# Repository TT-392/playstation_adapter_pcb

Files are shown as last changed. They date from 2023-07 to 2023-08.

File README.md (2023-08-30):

# RP2040 PlayStation adapter
This project is a simple PlayStation 1/2 controller port to USB C adapter. I made it so that I would be able to use it with the cheap, second hand, PlayStation 2, Taiko no Tatsujin drum, which I bought while in Japan.

I only wrote software for the Taiko drum, but in theory, all of the hardware is there to support a lot of different kinds of PlayStation controllers. The firmware can be found [here](https://github.com/TT-392/playstation_adapter_code).

## Using the hardware with non Taiko drum controllers
If you want to use this hardware with other PlayStation controllers, you are going to have to write your own firmware. For details on how to do this, I recommend the following source: [Interfacing a PS2 (PlayStation 2) Controller](https://store.curiousinventor.com/guides/PS2/).

One thing to keep in mind is power requirements of the controller you are using. I haven't found much information on how much power controllers pull (not that I put in that much effort), except for what is mentioned in the aforementioned source. Therefore, I can only give information on the power supply situation of this PCB.
* Pin 5 (power). This pin gets 3.3V through an AMS1117-3.3 voltage regulator. This voltage regulator is rated for 1A (though, this does assume that it is able to get rid of the heat), but that does assume that your USB port is able to supply that. Therefore, its power rating is, whatever your USB port is able to deliver if that is < 1A, otherwise 1A.
* Pin 3 (vibrator power). This pin is connected to the USB port VBUS pin (5V) through a 0 ohm resistor, so it can be enabled or disabled by placing or not placing that resistor. I don't know how this pin is usually used, because I only have a Taiko drum, and that drum doesn't have a vibration motor, but it felt like a good idea to give the option to leave it unconnected in case there exists a controller which pulls too much power for a USB port with the vibration motor powered, but not without it powered (assuming the controller would even work like that).
* I referred to USB power in those last 2 points. This table on [Wikipedia](https://en.wikipedia.org/wiki/USB#Power) should help you in figuring out what that is. Keep in mind that the type-c power delivery standards need extra communication between your device and the supply, and therefore cannot be used in this case. While with the BC 1.1 and 1.2 specs, you are supposed to check if there is a resistor between the D+ and D- lines to check if you are allowed to pull that much power, this PCB doesn't have the hardware to check that, but (although it is probably a bad idea), nothing is stopping you from pulling that much from ports capable of this.

## Ordering
I used JLCPCB to order my PCBs with all of their parts already pick and placed. I used [this](https://github.com/Bouni/kicad-jlcpcb-tools) plugin to do this. However, if you just want to order the same PCBs as I did, without any modifications, you can just grab the production files from the "JLCPCB" folder, or from the "releases" tab on github. The rest of this guide assumes you have your PCBs with the SMD components fully assembled at JLCPCB (nothing is stopping you from soldering them on yourself of course).

Apart from the PCBs, you should get your hands on some PlayStation controller ports with 90 degree pins. I got mine from [AliExpress](https://www.aliexpress.com/item/32818887920.html?spm=a2g0o.order_list.order_list_main.17.45ed1802iEjUwq) (AliExpress links rot quickly, but you should be able to find something similar). And some 9 pin, 3.96mm pitch pin header, I used [these](https://www.lcsc.com/product-detail/_BOOMELE-Boom-Precision-Elec-_C10586.html) (At the time of writing, you get free shipping on LCSC, if your recently ordered something from JLCPCB). And if you want some protection for your board, get some 50mm diameter heat-shrink (I got [this](https://www.aliexpress.com/item/1005002849810793.html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) stuff from AliExpress, seems to work well).

## assembly
If you followed the ordering instructions, you should now have a PCB that looks something like one of these:

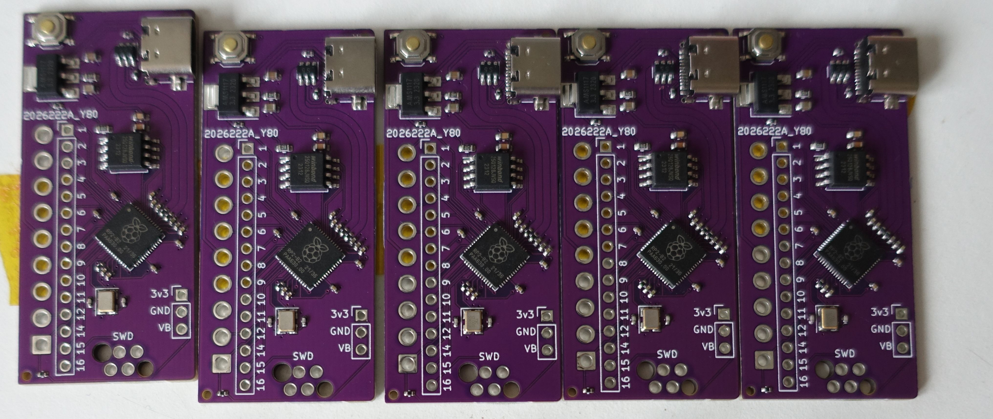
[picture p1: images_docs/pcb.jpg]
5 assembled PCBs with purple solder mask


Because the 90 degree PlayStation ports don't quite reach to the PCB, a we need something to bridge the gap. To do this, I decided to use some 3.96mm pitch, 9 pin pin headers, sadly, I couldn't find any without a plastic tab, so I just got the ones that looked like they had a tab that was easy to remove. So that is the first step in assembly, remove this tab, like is shown in the following image:

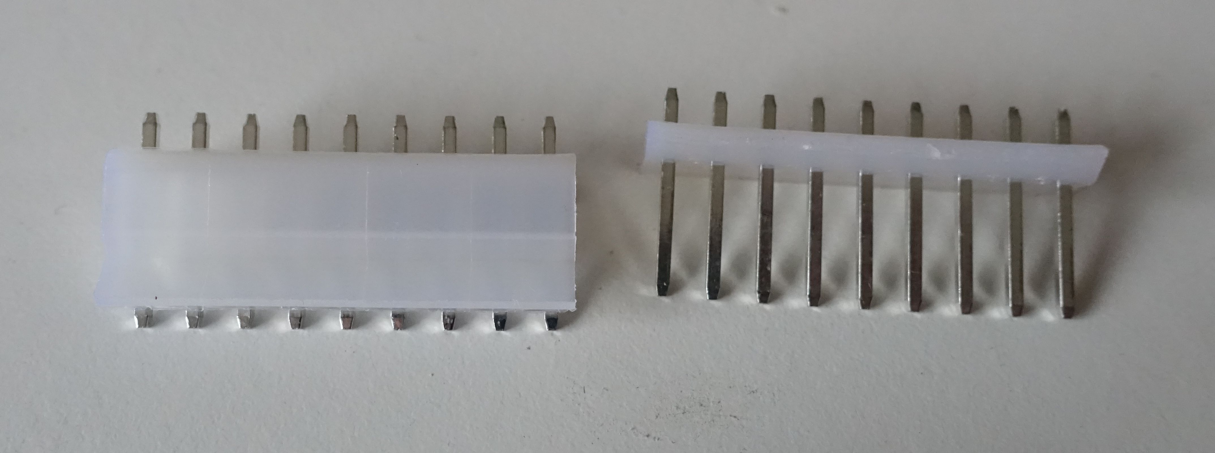
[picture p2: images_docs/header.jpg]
Two pin headers, one of them has the tab removed


Next, this header should be soldered to the PCB, I have found that it works best if you solder on the connector with the pins sticking out about 5 mm, and with the side of the connector that has the least plastic, pointing to the edge of the board, to allow for easier snipping later (I found out about this orientation trick in the next one I assembled, therefore the pictures have the connector rotated by 180 degrees compared to what I am saying here).

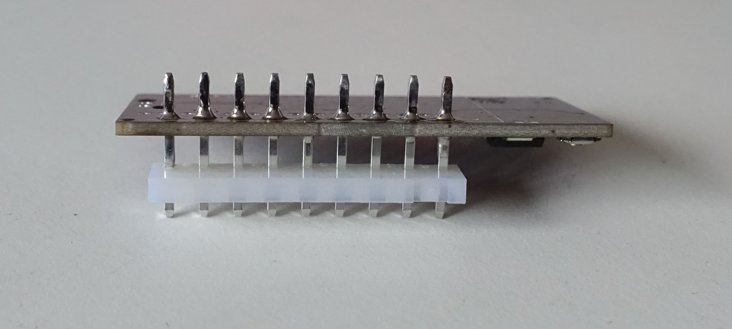
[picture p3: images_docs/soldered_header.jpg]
A side view of the PCB with the pin header installed, the plastic part of the pin header isn't flush with the surface of the PCB like it would normally be, but instead it is about 7 mm away from the surface.


Next, we glue (I used hot glue) the connector to the bottom side of the PCB, with the pins as close as possible to the pin header's pins, like shown in the following picture

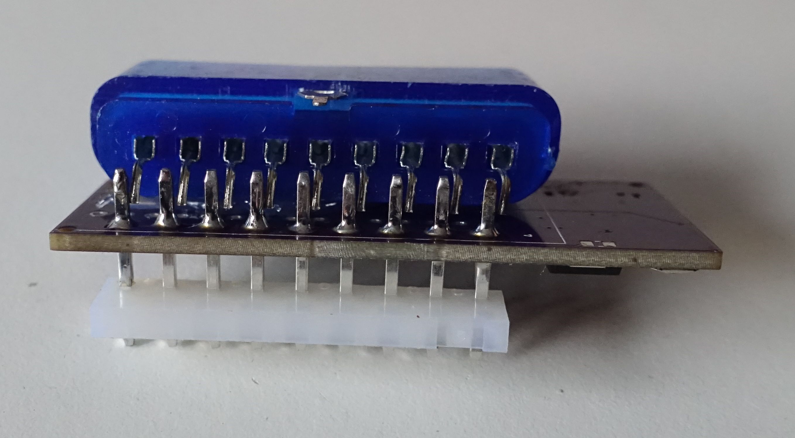
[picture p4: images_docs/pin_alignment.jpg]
Like the last picture, but with a blue PlayStation connector glued on the back of the PCB, close to touching the header pins from the side Like the last picture, but with a blue playstation connector glued on the back of the pcb, close to touching the header pins from the side


The next step is to solder these pins together, be sure to use ample solder, to make sure the pins really have a good connection.

After you have soldered these pins together, you can go ahead and use some side cutters to cut the pins of the connector on the other side of the board. The result of these two steps can be seen in the following image:

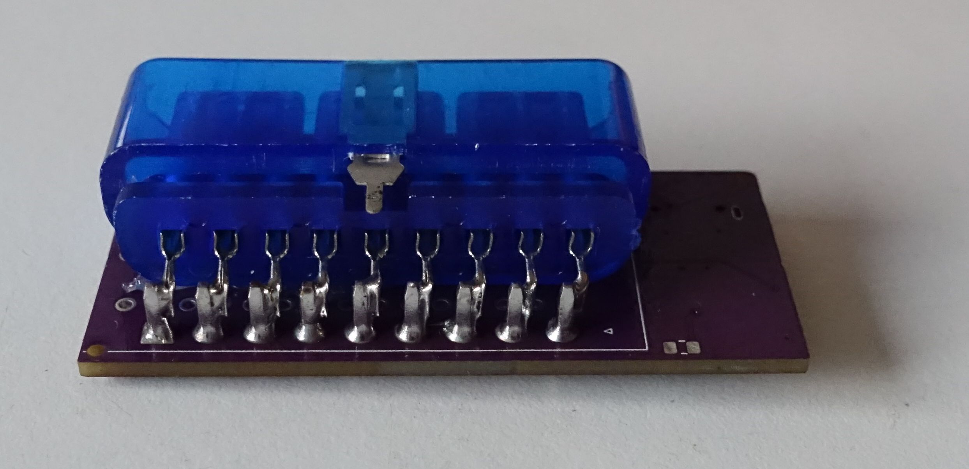
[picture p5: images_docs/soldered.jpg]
A view of the bottom side of the board, the pin header, and the PlayStation connector pins are soldered together. The excess part of the pin header on the other side of the board has been cut off A view of the bottom side of the board, the pin header, and the playstation connector pins are soldered together. The excess part of the pin header on the other side of the board has been cut off


Now it is time to heat shrink our adapter for some extra protection. Cut off a decent size piece of the heat shrink, so that the adapter can sit inside, with ample space on both sides:

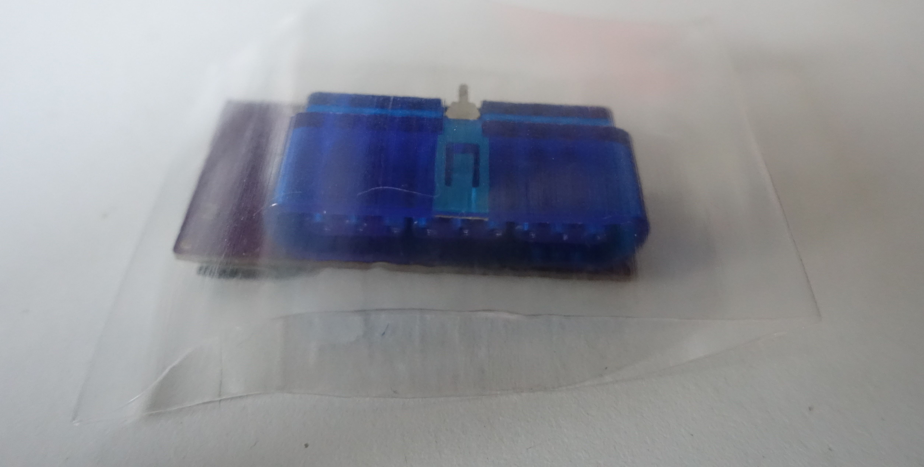
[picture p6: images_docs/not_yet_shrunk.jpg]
The assembled adapter sitting in a seemingly big piece of heat-shrink


Now use a heat gun to shrink the heat-shrink:

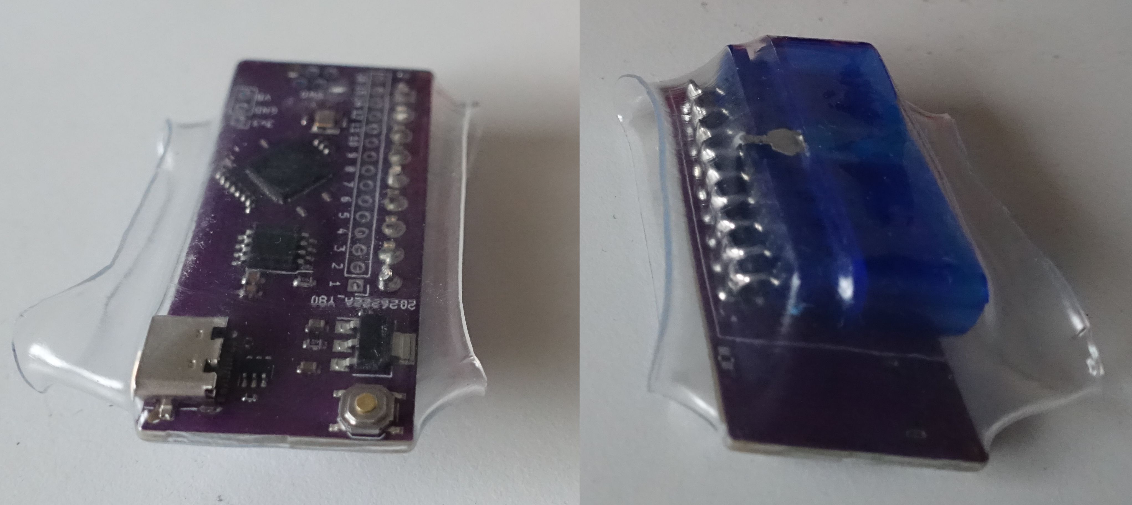
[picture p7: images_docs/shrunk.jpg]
The same as the previous image, but with the heat-shrink shrunk around the adapter


Now we can cut away the excess heat-shrink (I used normal scissors, just make sure they are scissors that close well), and we have our finished adapter:

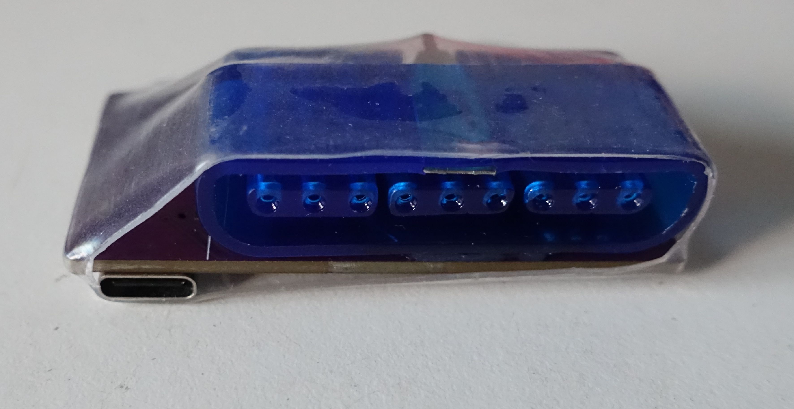
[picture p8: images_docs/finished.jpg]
The finished adapter


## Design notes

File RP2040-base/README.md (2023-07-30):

# RP2040-base
Basic drop in RP2040 kicad schematic sheet

# IMPORTANT
Not quite ready for use yet, for details, see notes.md.

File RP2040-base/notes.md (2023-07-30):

# Bugs
Not compliant with jlcpcb design rules
no explanation about the flash chip
Crystal is no longer a basic part? there seems to be a different 12MHz crystal in its place
jlcpcb doesn't have basic 27 ohm resistors

# Improvements
C4 could use a sligghtly better position (giving more space to GPIO0-7
U2 could be closer to U1
if chip were not at 45 degrees, that might have allowed for a smaller footprint
rp2040 3d model, add pi logo
jlcpcb part numbers

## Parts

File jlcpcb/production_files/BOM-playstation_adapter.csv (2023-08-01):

Comment | Designator | Footprint | LCSC
1k | R5 | R_0402_1005Metric | C11702
100n | C17 | C_0603_1608Metric | C14663
100n | C10,C11,C12,C3,C4,C5,C6,C7,C8,C9 | C_0402_1005Metric | C1525
30p | C15,C16 | C_0402_1005Metric | C1570
1u | C1 | C_0603_1608Metric | C15849
RP2040 | U3 | QFN-56-1EP_7x7mm_P0.4mm_EP3.2x3.2mm | C2040
1k | R6 | R_0603_1608Metric | C21190
1R | R1 | R_0603_1608Metric | C22936
27 | R3,R4 | R_0402_1005Metric | C25092
1k5 | R10,R9 | R_0402_1005Metric | C25867
5k1 | R7,R8 | R_0402_1005Metric | C25905
SW_Push | SW1 | TS-1187A | C318884
1u | C13,C14 | C_0402_1005Metric | C52923
10n | C18 | C_0603_1608Metric | C57112
22u | C2 | C_0603_1608Metric | C59461
AMS1117-3.3 | U1 | SOT-223-3_TabPin2_flipped_for_jlcpcb | C6186
SRV05-4 | U2 | SOT-23-6_flipped_for_jlcpcb | C85364
X322512MSB4SI | Y1 | YSX321SL, datasheet recommended measurements | C9002
GT-USB-7047C | J3 | GT-USB-7047C | C963218
W25QXXXJV | U4 | SOIC-8_5.275x5.275mm_P1.27mm | C97521
Conn_01x03 | J1 | PinHeader_1x03_P2.54mm_Vertical
0, DNF | R2 | R_0805_2012Metric
Conn_01x04 | SWD1 | REDFIT 4 pin
Conn_01x13 | J2 | PinHeader_1x15_P2.54mm_Vertical_no_courtyard
~ | J4 | PSX port

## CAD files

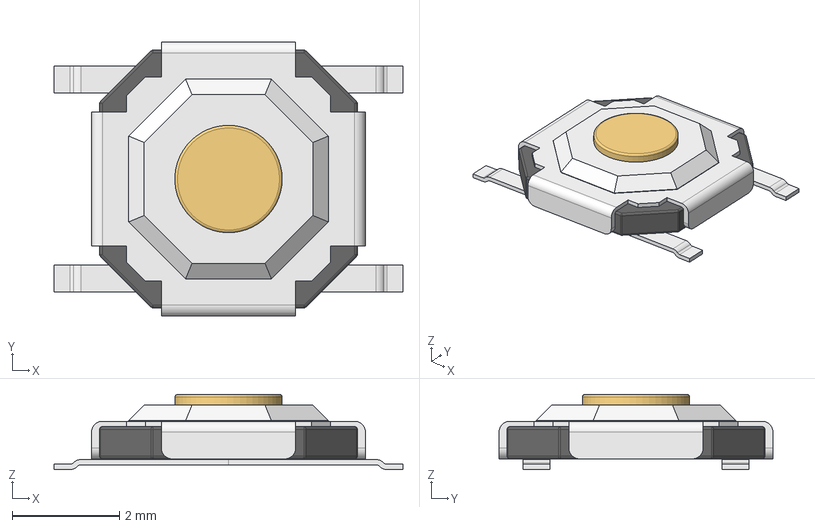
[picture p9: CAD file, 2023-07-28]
RP2040-base/RP2040_base_libs/TS-1187A.step
6.50 x 5.10 x 1.40 mm
Plastic base
Button

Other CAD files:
RP2040-base/RP2040_base_libs/TS-1187A.FCStd

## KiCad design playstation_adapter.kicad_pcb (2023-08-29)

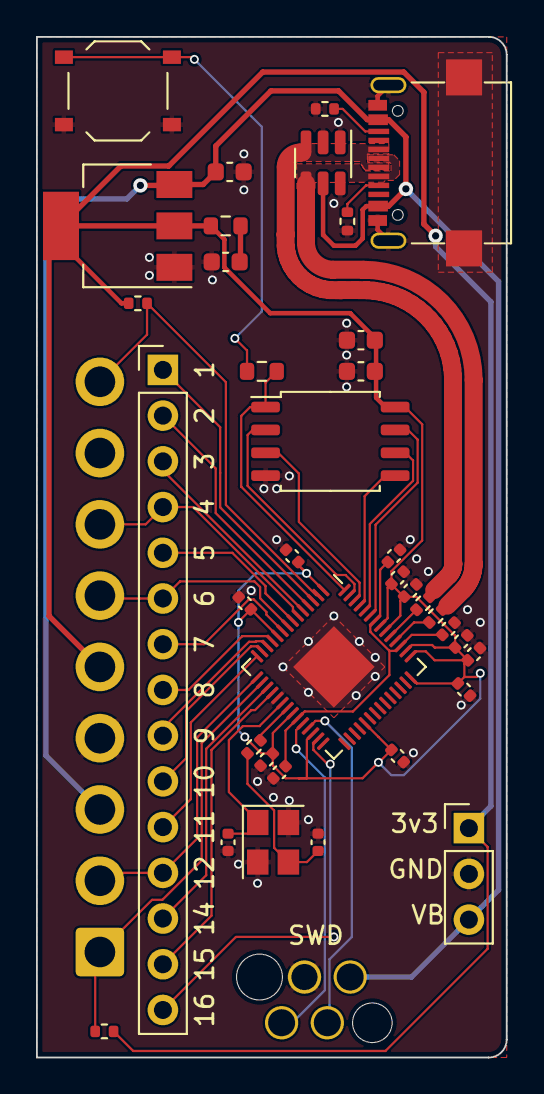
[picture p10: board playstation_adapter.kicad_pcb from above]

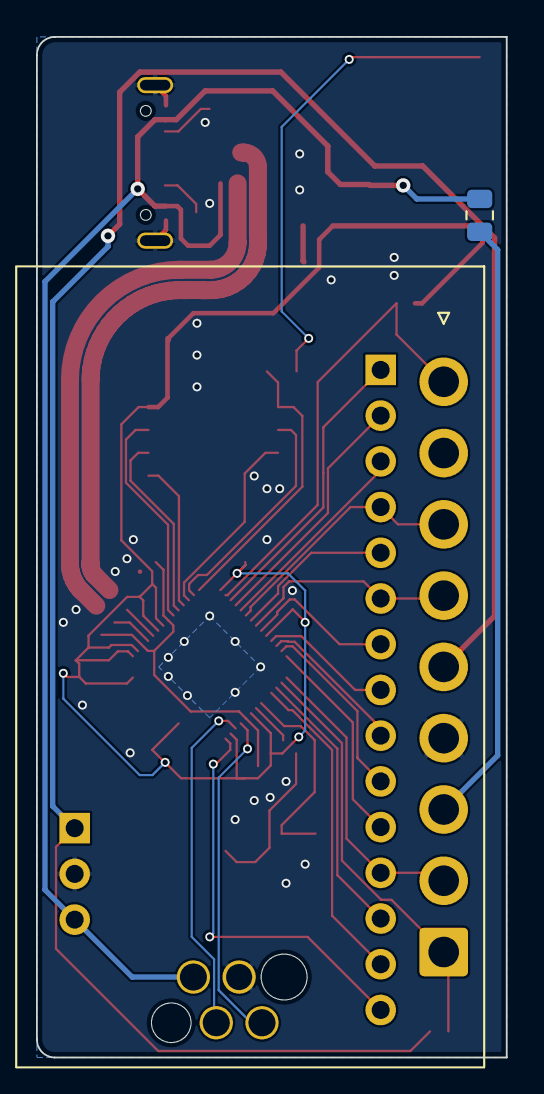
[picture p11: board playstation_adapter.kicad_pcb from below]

Board: 2 copper layers, 26.1 x 56.7 mm, 39 parts (2 on the bottom side), 41 nets.

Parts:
C1: 1u; C_0603_1608Metric
C2: 22u; C_0603_1608Metric
C3, C4, C5, C6, C7, C8, C9, C10, C11, C12: 100n; C_0402_1005Metric
C13, C14: 1u; C_0402_1005Metric
C15, C16: 30p; C_0402_1005Metric
C17: 100n; C_0603_1608Metric
C18: 10n; C_0603_1608Metric
J1: Conn_01x03; PinHeader_1x03_P2.54mm_Vertical
J2: Conn_01x13; PinHeader_1x15_P2.54mm_Vertical_no_courtyard
J3: GT-USB-7047C
J4: PSX port
R1: 1R; R_0603_1608Metric
R2: 0, DNF; R_0805_2012Metric
R3, R4: 27; R_0402_1005Metric
R5: 1k; R_0402_1005Metric
R6: 1k; R_0603_1608Metric
R7, R8: 5k1; R_0402_1005Metric
R9, R10: 1k5; R_0402_1005Metric
SW1: SW_Push; TS-1187A
SWD1: Conn_01x04; REDFIT 4 pin
U1: AMS1117-3.3; SOT-223-3_TabPin2_flipped_for_jlcpcb
U2: SRV05-4; SOT-23-6_flipped_for_jlcpcb
U3: RP2040; QFN-56-1EP_7x7mm_P0.4mm_EP3.2x3.2mm
U4: W25QXXXJV; SOIC-8_5.275x5.275mm_P1.27mm
Y1: X322512MSB4SI; YSX321SL, datasheet recommended measurements

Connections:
+3V3: C5.1, C6.1, C7.1, C8.1, C9.1, C10.1, C11.1, C12.1, C14.1, C17.1, C18.1, J1.1, J4.5 (pwr), R1.1, R9.1, R10.1, U1.2 (VO), U3.1 (IOVDD), U3.10 (IOVDD), U3.22 (IOVDD), U3.26 (RUN), U3.33 (IOVDD), U3.42 (IOVDD), U3.43 (ADC_AVDD), U3.44 (VREG_IN), U3.48 (USB_VDD), U3.49 (IOVDD), U4.8 (VCC)
/RP2040-base/1V1: C3.1, C4.1, C13.1, U3.23 (DVDD), U3.45 (VREG_VOUT), U3.50 (DVDD)
/RP2040-base/GPIO0: J4.9 (ack), R10.2, U3.2 (GPIO0)
/RP2040-base/GPIO1: J2.1, U3.3 (GPIO1)
/RP2040-base/GPIO2: J2.2, U3.4 (GPIO2)
/RP2040-base/GPIO3: J2.3, U3.5 (GPIO3)
/RP2040-base/GPIO4: J2.4, J4.7 (clk), U3.6 (GPIO4)
/RP2040-base/GPIO5: J2.5, U3.7 (GPIO5)
/RP2040-base/GPIO6: J2.6, J4.6 (att), U3.8 (GPIO6)
/RP2040-base/GPIO7: J2.7, U3.9 (GPIO7)
/RP2040-base/GPIO8: J2.8, U3.11 (GPIO8)
/RP2040-base/GPIO9: J2.9, U3.12 (GPIO9)
/RP2040-base/GPIO10: J2.10, U3.13 (GPIO10)
/RP2040-base/GPIO11: J2.11, U3.14 (GPIO11)
/RP2040-base/GPIO12: J2.12, J4.2 (cmd), U3.15 (GPIO12)
/RP2040-base/GPIO13: J4.1 (data), R9.2, U3.16 (GPIO13)
/RP2040-base/GPIO14: J2.13, U3.17 (GPIO14)
/RP2040-base/GPIO15: J2.14, U3.18 (GPIO15)
/RP2040-base/GPIO16: J2.15, U3.27 (GPIO16)
/RP2040-base/QSPI_SCLK: U3.52 (QSPI_SCLK), U4.6 (CLK)
/RP2040-base/QSPI_SD0: U3.53 (QSPI_SD0), U4.5 (DI(IO0))
/RP2040-base/QSPI_SD1: U3.55 (QSPI_SD1), U4.2 (DO(IO1))
/RP2040-base/QSPI_SD2: U3.54 (QSPI_SD2), U4.3 (IO2)
/RP2040-base/QSPI_SD3: U3.51 (QSPI_SD3), U4.7 (IO3)
/RP2040-base/QSPI_SS: R6.1, U3.56 (QSPI_SS), U4.1 (~CS)
/RP2040-base/SWCLK: SWD1.1, U3.24 (SWCLK)
/RP2040-base/SWD: SWD1.3, U3.25 (SWD)
/RP2040-base/USB_D+: J3.A6 (D+), J3.B6 (D+), R3.1, U2.3 (IO2)
/RP2040-base/USB_D-: J3.A7 (D-), J3.B7 (D-), R4.1, U2.4 (IO3)
/RP2040-base/XIN: C15.1, U3.20 (XIN), Y1.1
/RP2040-base/XOUT: R5.1, U3.21 (XOUT)
/RP2040-base/~USB_BOOT: R6.2, SW1.2
/vibrator power: J4.3 (vpwr), R2.2
GND: C1.2, C2.2, C3.2, C4.2, C5.2, C6.2, C7.2, C8.2, C9.2, C10.2, C11.2, C12.2, C13.2, C14.2, C15.2, C16.2, C17.2, C18.2, J1.2, J3.A1 (GND), J3.A12 (GND), J3.B1 (GND), J3.B12 (GND), J3.S1 (SHIELD), J4.4 (gnd), R7.2, R8.2, SW1.1, SWD1.2, U1.1 (GND), U2.1 (IO1), U2.2 (VN), U2.6 (IO4), U3.19 (TESTEN), U3.57 (GND), U4.4 (GND), Y1.2, Y1.4
unnamed: C2.1, R1.2
unnamed: C16.1, R5.2, Y1.3
unnamed: J3.A5 (CC1), R7.1
unnamed: J3.B5 (CC2), R8.1
unnamed: R4.2, U3.46 (USB_DM)
unnamed: R3.2, U3.47 (USB_DP)
VBUS: C1.1, J1.3, J3.A4 (VBUS), J3.A9 (VBUS), J3.B4 (VBUS), J3.B9 (VBUS), R2.1, SWD1.4, U1.3 (VI), U2.5 (VP)

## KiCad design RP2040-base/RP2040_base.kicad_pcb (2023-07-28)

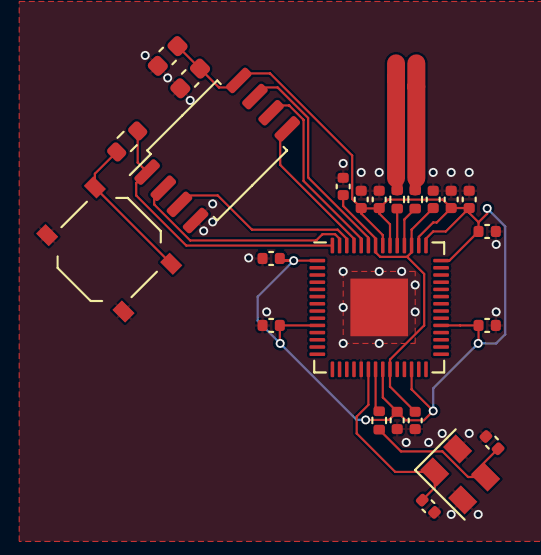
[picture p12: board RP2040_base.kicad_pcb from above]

Board: 2 copper layers, 24 parts (0 on the bottom side), 15 nets.

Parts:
C1, C2, C3, C4, C5, C8, C9, C18, C19, C28: 100n; C_0402_1005Metric
C6, C7: 1u; C_0402_1005Metric
C29: 100n; C_0603_1608Metric
C30: 10n; C_0603_1608Metric
C31, C32: 30p; C_0402_1005Metric
R6, R7: 27; R_0402_1005Metric
R8: 1k; R_0603_1608Metric
R10: 1k; R_0402_1005Metric
SW1: SW_Push; TS-1187A
U1: W25Q16JV; SOIC-8_5.275x5.275mm_P1.27mm
U2: RP2040; QFN-56-1EP_7x7mm_P0.4mm_EP3.2x3.2mm
Y2: ECS-120-8-33-JGN-TR3; Crystal_SMD_EuroQuartz_MT-4Pin_3.2x2.5mm

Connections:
/1V1: C6.1, C18.1, C19.1, U2.23 (DVDD), U2.45 (VREG_VOUT), U2.50 (DVDD)
/GND: C1.2, C2.2, C3.2, C4.2, C5.2, C6.2, C7.2, C8.2, C9.2, C18.2, C19.2, C28.2, C29.2, C30.2, C31.2, C32.2, SW1.1, U1.4 (GND), U2.19 (TESTEN), U2.57 (GND), Y2.2, Y2.4
/QSPI_SCLK: U1.6 (CLK), U2.52 (QSPI_SCLK)
/QSPI_SD0: U1.5 (DI(IO0)), U2.53 (QSPI_SD0)
/QSPI_SD1: U1.2 (DO(IO1)), U2.55 (QSPI_SD1)
/QSPI_SD2: U1.3 (IO2), U2.54 (QSPI_SD2)
/QSPI_SD3: U1.7 (IO3), U2.51 (QSPI_SD3)
/QSPI_SS: R8.1, U1.1 (~CS), U2.56 (QSPI_SS)
/VIN: C1.1, C2.1, C3.1, C4.1, C5.1, C7.1, C8.1, C9.1, C28.1, C29.1, C30.1, U1.8 (VCC), U2.1 (IOVDD), U2.10 (IOVDD), U2.22 (IOVDD), U2.26 (RUN), U2.33 (IOVDD), U2.42 (IOVDD), U2.43 (ADC_AVDD), U2.44 (VREG_IN), U2.48 (USB_VDD), U2.49 (IOVDD)
/XIN: C31.1, U2.20 (XIN), Y2.1
/XOUT: R10.1, U2.21 (XOUT)
/~USB_BOOT: R8.2, SW1.2
unnamed: C32.1, R10.2, Y2.3
unnamed: R7.2, U2.46 (USB_DM)
unnamed: R6.2, U2.47 (USB_DP)

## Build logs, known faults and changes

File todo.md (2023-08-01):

Move PSX port to different lib, to clarify license
Either clarify that this device isn't made for other controllers, or make sure it can handle the power needs from other controllers

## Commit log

2023-07-22 Rev 0.1
    [RP2040_base.kicad_pcb, RP2040_base.kicad_sch]
2023-07-22 Add git url
    [RP2040_base.kicad_sch]
2023-07-28 Create sample pcb layout, manage schematic files better, and fill in missing 3d model.
    [RP2040_base.kicad_pcb, RP2040_base.kicad_sch, TS-1187A.FCStd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]
2023-07-28 Fix some bugs in RP2040-base
    [RP2040_base.kicad_pcb, RP2040_base.kicad_sch]
2023-07-28 Add second path to 3d model, one directory deeper, to allow for the model to be used from a project in a lower directory.
    [RP2040_base.kicad_pcb]
2023-07-28 Fix GPIO29_ADC3 pin name
    [RP2040_base.kicad_sch]
2023-07-28 Expose pins through bus instead
    [RP2040_base.kicad_sch]
2023-07-29 Finish schematic
    [RP2040_base_example.kicad_pcb, RP2040_base_example.kicad_sch]
2023-07-30 Swap crystal
    [RP2040_base.kicad_sch]
2023-07-30 Complete pcb + jlcpcb production files for part placement test on website
    [BOM-RP2040_base_example.csv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]
2023-07-30 Add termination resistor note
2023-07-30 Rotate footprints to coincide with jlcpcb rotation
    [RP2040_base.kicad_sch]
2023-07-30 Add title blocks, and set version to 0.9 (will bump to 1.0 if ordered and tested)
    [RP2040_base_example.kicad_pcb, RP2040_base_example.kicad_sch]
2023-07-30 Fix date
    [RP2040_base.kicad_sch]
2023-07-30 Rename project and modify license
    [playstation_adapter-CuBottom.gbr, playstation_adapter-CuTop.gbr, playstation_adapter-EdgeCuts.gbr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]
2023-08-01 Modified example pcb to playstation adapter pcb
    [BOM-playstation_adapter.csv, RP2040_base.kicad_sch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]
2023-08-29 Bump version number after having ordered and tested pcb
    [playstation_adapter.kicad_pcb, playstation_adapter.kicad_sch]
